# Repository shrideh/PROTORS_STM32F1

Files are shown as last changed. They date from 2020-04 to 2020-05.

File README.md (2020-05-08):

# PROTORS_STM32F1
This is a repository of our **open-source board** based on the *STM32F103C8 microcontroller from STMicroelectronics*.

<p align="center">
  
</p>

## Pinout and dimensions
For the available functions of every pin, we strongly encourage you to read the [microcontroller datasheet](https://www.st.com/resource/en/datasheet/stm32f103c8.pdf), or use `variant/variant.h` and `variant/PeripherialPins.c` files.

<p align="center">
  
</p>

## Electronics
* Whole *KiCad project* is available in `PROTORS_STM32F1` folder.

## Requirements
[Arduino](https://www.arduino.cc/)<br>
[Arduino_Core_STM32](https://github.com/stm32duino/Arduino_Core_STM32)<br>

This board is tested with
**Arduino IDE 1.8.12** and **Arduino_Core_STM32 1.8.0**.

## Installation & Usage
To use this board within [Arduino IDE](https://www.arduino.cc/en/main/software) you need [STM32 core support for Arduino](https://github.com/stm32duino/Arduino_Core_STM32). Every new board is called *variant*, to add this variant to list, you first need to find out where are source files on your system (follow [Where are sources](https://github.com/stm32duino/wiki/wiki/Where-are-sources#stm32-core-sources-files-location) page).

* Create folder `PROTORS_STM32F1` in `variants` folder and copy all files from this repositories `variant` folder (`ldscript.ld`, `PeripheralPins.c`, `PinNamesVar.h`, `variant.cpp`, and `variant.h`).
* Append `boards_additional.txt` content to `boards.txt` file (it is in same folder as `variant` folder), to declare the new variant.
* Restart *Arduino IDE* and try your new board. From ***Tools/Board*** menu select `Generic STM32F1 series` then from ***Tools/Board part number*** select `PROTORS STM32F1`. Set all of the rest options and upload sketch using ***STM32CubeProgrammer (SWD)*** (ST-LINK/V2 programmer).
* It is possible to customize some core definitions or compiler options by adding a file named `build_opt.h` in the sketch directory (follow [Build options](https://github.com/stm32duino/wiki/wiki/Customize-build-options-using-build_opt.h) page)

## License
Copyright (C) 2020 PROTORS  <info@protors.co>

Licensed under CERN-OHL-P version 2

You may redistribute and modify this documentation and make products
using it under the terms of the [CERN-OHL-P v2](https://ohwr.org/project/cernohl/wikis/Documents/CERN-OHL-version-2).
This documentation is distributed WITHOUT ANY EXPRESS OR IMPLIED
WARRANTY, INCLUDING OF MERCHANTABILITY, SATISFACTORY QUALITY
AND FITNESS FOR A PARTICULAR PURPOSE. Please see the CERN-OHL-P v2
for applicable conditions.

For more information view [LICENSE.txt](./LICENSE.txt) file.

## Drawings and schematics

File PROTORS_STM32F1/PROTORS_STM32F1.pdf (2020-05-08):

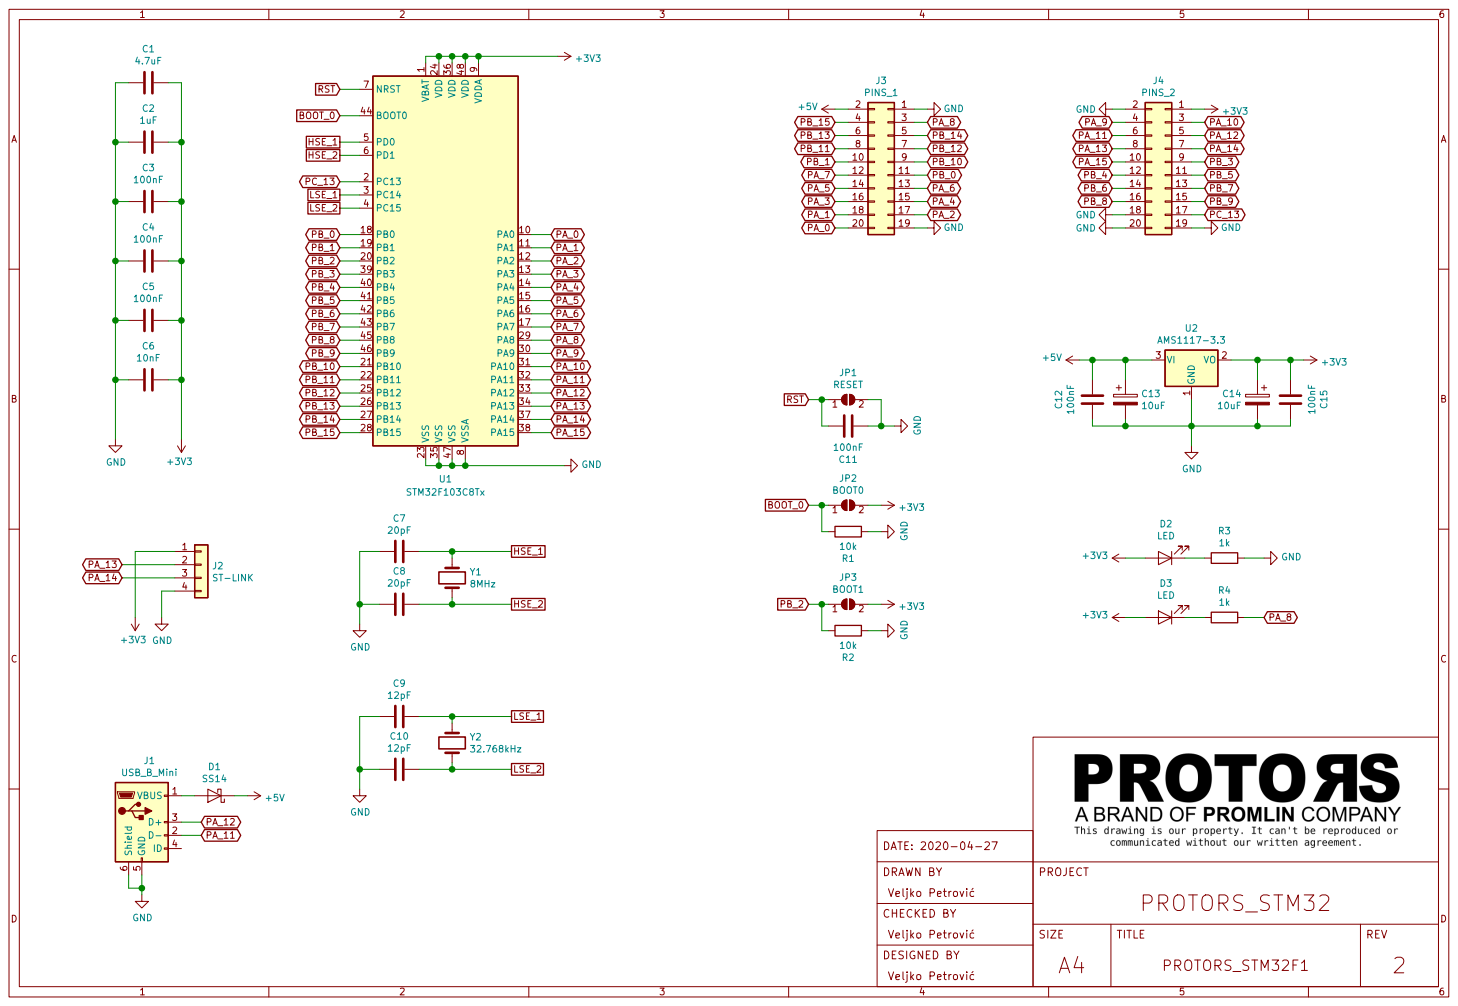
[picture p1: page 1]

DESIGNED BY CHECKED BY DRAWN BY

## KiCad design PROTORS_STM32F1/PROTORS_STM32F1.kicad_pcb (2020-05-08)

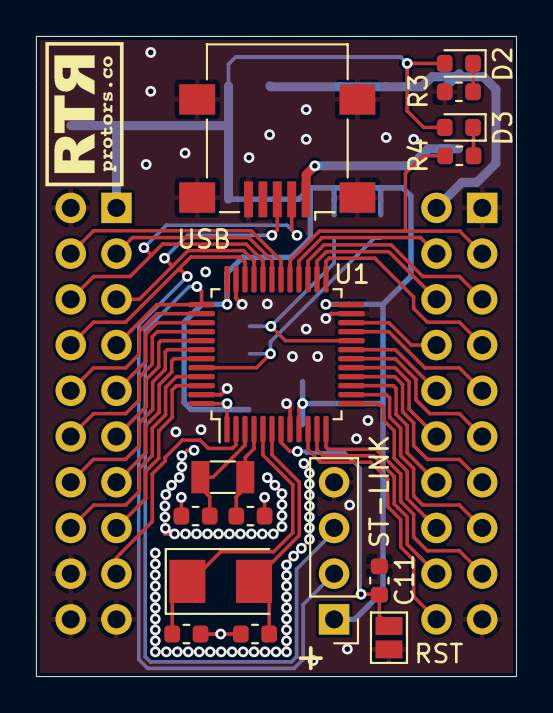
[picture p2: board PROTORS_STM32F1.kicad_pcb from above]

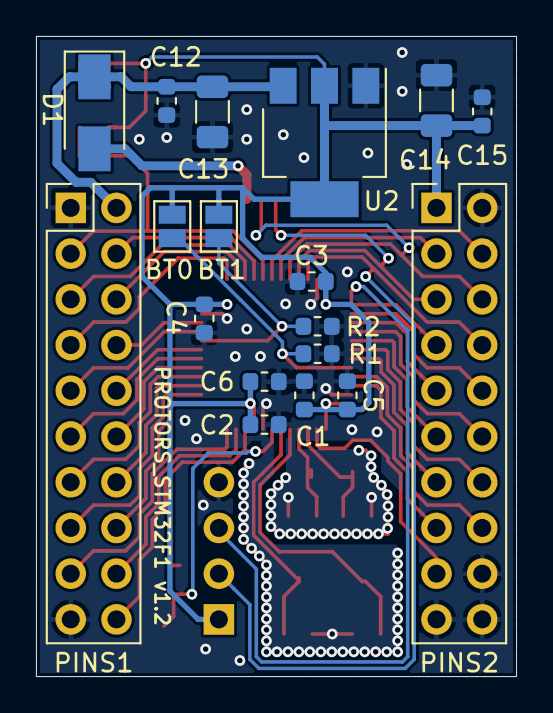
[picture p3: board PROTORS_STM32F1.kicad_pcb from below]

Board: 2 copper layers, 26.7 x 35.6 mm, 33 parts (18 on the bottom side), 45 nets.

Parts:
BT0: BOOT0; SolderJumper-2_P1.3mm_Open_Pad1.0x1.5mm
BT1: BOOT1; SolderJumper-2_P1.3mm_Open_Pad1.0x1.5mm
C1: 4.7uF; C_0603_1608Metric
C2: 1uF; C_0603_1608Metric
C3, C4, C5, C11, C12, C15: 100nF; C_0603_1608Metric
C6: 10nF; C_0603_1608Metric
C7, C8: 20pF; C_0603_1608Metric
C9, C10: 12pF; C_0603_1608Metric
C13, C14: 10uF; C_1206_3216Metric
D1: SS14; D_SMA
D2, D3: LED; LED_0603_1608Metric
PINS1: PINS_1; PinHeader_2x10_P2.54mm_Vertical
PINS2: PINS_2; PinHeader_2x10_P2.54mm_Vertical
R1, R2: 10k; R_0603_1608Metric
R3, R4: 1k; R_0603_1608Metric
RST: RESET; SolderJumper-2_P1.3mm_Open_Pad1.0x1.5mm
ST-LINK: ST-LINK; PinHeader_1x04_P2.54mm_Vertical
U1: STM32F103C8Tx; LQFP-48_7x7mm_P0.5mm
U2: AMS1117-3.3; SOT-223-3_TabPin2
USB: USB_B_Mini; USB_Mini-B_Lumberg_2486_01_Horizontal
Y1: 8MHz; Crystal_SMD_5032-2Pin_5.0x3.2mm
Y2: 32.768kHz; Crystal_SMD_3215-2Pin_3.2x1.5mm

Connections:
+3V3: BT0.2, BT1.2, C1.2, C2.2, C3.2, C4.2, C5.2, C6.2, C14.1, C15.1, D2.2, D3.2, PINS2.1, ST-LINK.1, U1.1, U1.9, U1.24, U1.36, U1.48, U2.2
+5V: C12.2, C13.1, D1.1, PINS1.2, U2.3
BOOT_0: BT0.1, R1.1, U1.44
GND: C1.1, C2.1, C3.1, C4.1, C5.1, C6.1, C7.2, C8.2, C9.2, C10.2, C11.1, C12.1, C13.2, C14.2, C15.2, PINS1.1, PINS1.19, PINS2.2, PINS2.18, PINS2.19, PINS2.20, R1.2, R2.2, R3.1, RST.2, ST-LINK.4, U1.8, U1.23, U1.35, U1.47, U2.1, USB.5, USB.6
HSE_1: C7.1, U1.5, Y1.1
HSE_2: C8.1, U1.6, Y1.2
LSE_1: C9.1, U1.3, Y2.1
LSE_2: C10.1, U1.4, Y2.2
unnamed: D1.2, USB.1
unnamed: D2.1, R3.2
unnamed: D3.1, R4.2
PA_0: PINS1.20, U1.10
PA_1: PINS1.18, U1.11
PA_2: PINS1.17, U1.12
PA_3: PINS1.16, U1.13
PA_4: PINS1.15, U1.14
PA_5: PINS1.14, U1.15
PA_6: PINS1.13, U1.16
PA_7: PINS1.12, U1.17
PA_8: PINS1.3, R4.1, U1.29
PA_9: PINS2.4, U1.30
PA_10: PINS2.3, U1.31
PA_11: PINS2.6, U1.32, USB.2
PA_12: PINS2.5, U1.33, USB.3
PA_13: PINS2.8, ST-LINK.2, U1.34
PA_14: PINS2.7, ST-LINK.3, U1.37
PA_15: PINS2.10, U1.38
PB_0: PINS1.11, U1.18
PB_1: PINS1.10, U1.19
PB_2: BT1.1, R2.1, U1.20
PB_3: PINS2.9, U1.39
PB_4: PINS2.12, U1.40
PB_5: PINS2.11, U1.41
PB_6: PINS2.14, U1.42
PB_7: PINS2.13, U1.43
PB_8: PINS2.16, U1.45
PB_9: PINS2.15, U1.46
PB_10: PINS1.9, U1.21
PB_11: PINS1.8, U1.22
PB_12: PINS1.7, U1.25
PB_13: PINS1.6, U1.26
PB_14: PINS1.5, U1.27
PB_15: PINS1.4, U1.28
PC_13: PINS2.17, U1.2
RST: C11.2, RST.1, U1.7

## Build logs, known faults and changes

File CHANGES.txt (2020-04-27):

--------------------
PROTORS_STM32F1 - Open-source board 
based on the STM32F103C8 microcontroller from STMicroelectronics.
--------------------

Release 1.0.0, 27.04.2020.

- Initial release

--------------------

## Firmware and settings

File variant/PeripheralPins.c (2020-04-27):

/*
 *******************************************************************************
 * Copyright (c) 2019, STMicroelectronics
 * All rights reserved.
 *
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
 * THIS SOFTWARE IS PROVIDED BY THE COPYRIGHT HOLDERS AND CONTRIBUTORS "AS IS"
 * AND ANY EXPRESS OR IMPLIED WARRANTIES, INCLUDING, BUT NOT LIMITED TO, THE
 * IMPLIED WARRANTIES OF MERCHANTABILITY AND FITNESS FOR A PARTICULAR PURPOSE ARE
 * DISCLAIMED. IN NO EVENT SHALL THE COPYRIGHT HOLDER OR CONTRIBUTORS BE LIABLE
 * FOR ANY DIRECT, INDIRECT, INCIDENTAL, SPECIAL, EXEMPLARY, OR CONSEQUENTIAL
 * DAMAGES (INCLUDING, BUT NOT LIMITED TO, PROCUREMENT OF SUBSTITUTE GOODS OR
 * SERVICES; LOSS OF USE, DATA, OR PROFITS; OR BUSINESS INTERRUPTION) HOWEVER
 * CAUSED AND ON ANY THEORY OF LIABILITY, WHETHER IN CONTRACT, STRICT LIABILITY,
 * OR TORT (INCLUDING NEGLIGENCE OR OTHERWISE) ARISING IN ANY WAY OUT OF THE USE
 * OF THIS SOFTWARE, EVEN IF ADVISED OF THE POSSIBILITY OF SUCH DAMAGE.
 *******************************************************************************
 * Automatically generated from STM32F103C(4-6)|(8-B)Tx.xml
 */
#include "Arduino.h"
#include "PeripheralPins.h"

/* =====
 * Note: Commented lines are alternative possibilities which are not used per default.
 *       If you change them, you will have to know what you do
 * =====
 */

//*** ADC ***

#ifdef HAL_ADC_MODULE_ENABLED
WEAK const PinMap PinMap_ADC[] = {
  {PA_0,  ADC1,  STM_PIN_DATA_EXT(STM_MODE_ANALOG, GPIO_NOPULL, 0, 0, 0)}, // ADC1_IN0
  //  {PA_0,  ADC2,  STM_PIN_DATA_EXT(STM_MODE_ANALOG, GPIO_NOPULL, 0, 0, 0)}, // ADC2_IN0
  {PA_1,  ADC1,  STM_PIN_DATA_EXT(STM_MODE_ANALOG, GPIO_NOPULL, 0, 1, 0)}, // ADC1_IN1
  //  {PA_1,  ADC2,  STM_PIN_DATA_EXT(STM_MODE_ANALOG, GPIO_NOPULL, 0, 1, 0)}, // ADC2_IN1
  {PA_2,  ADC1,  STM_PIN_DATA_EXT(STM_MODE_ANALOG, GPIO_NOPULL, 0, 2, 0)}, // ADC1_IN2
  //  {PA_2,  ADC2,  STM_PIN_DATA_EXT(STM_MODE_ANALOG, GPIO_NOPULL, 0, 2, 0)}, // ADC2_IN2
  {PA_3,  ADC1,  STM_PIN_DATA_EXT(STM_MODE_ANALOG, GPIO_NOPULL, 0, 3, 0)}, // ADC1_IN3
  //  {PA_3,  ADC2,  STM_PIN_DATA_EXT(STM_MODE_ANALOG, GPIO_NOPULL, 0, 3, 0)}, // ADC2_IN3
  {PA_4,  ADC1,  STM_PIN_DATA_EXT(STM_MODE_ANALOG, GPIO_NOPULL, 0, 4, 0)}, // ADC1_IN4
  //  {PA_4,  ADC2,  STM_PIN_DATA_EXT(STM_MODE_ANALOG, GPIO_NOPULL, 0, 4, 0)}, // ADC2_IN4
  {PA_5,  ADC1,  STM_PIN_DATA_EXT(STM_MODE_ANALOG, GPIO_NOPULL, 0, 5, 0)}, // ADC1_IN5
  //  {PA_5,  ADC2,  STM_PIN_DATA_EXT(STM_MODE_ANALOG, GPIO_NOPULL, 0, 5, 0)}, // ADC2_IN5
  {PA_6,  ADC1,  STM_PIN_DATA_EXT(STM_MODE_ANALOG, GPIO_NOPULL, 0, 6, 0)}, // ADC1_IN6
  //  {PA_6,  ADC2,  STM_PIN_DATA_EXT(STM_MODE_ANALOG, GPIO_NOPULL, 0, 6, 0)}, // ADC2_IN6
  {PA_7,  ADC1,  STM_PIN_DATA_EXT(STM_MODE_ANALOG, GPIO_NOPULL, 0, 7, 0)}, // ADC1_IN7
  //  {PA_7,  ADC2,  STM_PIN_DATA_EXT(STM_MODE_ANALOG, GPIO_NOPULL, 0, 7, 0)}, // ADC2_IN7
  {PB_0,  ADC1,  STM_PIN_DATA_EXT(STM_MODE_ANALOG, GPIO_NOPULL, 0, 8, 0)}, // ADC1_IN8
  //  {PB_0,  ADC2,  STM_PIN_DATA_EXT(STM_MODE_ANALOG, GPIO_NOPULL, 0, 8, 0)}, // ADC2_IN8
  {PB_1,  ADC1,  STM_PIN_DATA_EXT(STM_MODE_ANALOG, GPIO_NOPULL, 0, 9, 0)}, // ADC1_IN9
  //  {PB_1,  ADC2,  STM_PIN_DATA_EXT(STM_MODE_ANALOG, GPIO_NOPULL, 0, 9, 0)}, // ADC2_IN9
  {NC,    NP,    0}
};
#endif

//*** No DAC ***

//*** I2C ***

#ifdef HAL_I2C_MODULE_ENABLED
WEAK const PinMap PinMap_I2C_SDA[] = {
  {PB_7,  I2C1, STM_PIN_DATA(STM_MODE_AF_OD, GPIO_NOPULL, AFIO_NONE)},
  {PB_9,  I2C1, STM_PIN_DATA(STM_MODE_AF_OD, GPIO_NOPULL, AFIO_I2C1_ENABLE)},
#ifndef ARDUINO_BLUEPILL_F103C6
  {PB_11, I2C2, STM_PIN_DATA(STM_MODE_AF_OD, GPIO_NOPULL, AFIO_NONE)},
#endif
  {NC,    NP,    0}
};
#endif

#ifdef HAL_I2C_MODULE_ENABLED
WEAK const PinMap PinMap_I2C_SCL[] = {
  {PB_6,  I2C1, STM_PIN_DATA(STM_MODE_AF_OD, GPIO_NOPULL, AFIO_NONE)},
  {PB_8,  I2C1, STM_PIN_DATA(STM_MODE_AF_OD, GPIO_NOPULL, AFIO_I2C1_ENABLE)},
#ifndef ARDUINO_BLUEPILL_F103C6
  {PB_10, I2C2, STM_PIN_DATA(STM_MODE_AF_OD, GPIO_NOPULL, AFIO_NONE)},
#endif
  {NC,    NP,    0}
};
#endif

//*** PWM ***
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

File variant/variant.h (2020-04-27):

/*
 * PROTORS_STM32F1 
 *
 *******************************************************************************
 * Copyright (c) 2018, STMicroelectronics
 * All rights reserved.
 *
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
 * THIS SOFTWARE IS PROVIDED BY THE COPYRIGHT HOLDERS AND CONTRIBUTORS "AS IS"
 * AND ANY EXPRESS OR IMPLIED WARRANTIES, INCLUDING, BUT NOT LIMITED TO, THE
 * IMPLIED WARRANTIES OF MERCHANTABILITY AND FITNESS FOR A PARTICULAR PURPOSE ARE
 * DISCLAIMED. IN NO EVENT SHALL THE COPYRIGHT HOLDER OR CONTRIBUTORS BE LIABLE
 * FOR ANY DIRECT, INDIRECT, INCIDENTAL, SPECIAL, EXEMPLARY, OR CONSEQUENTIAL
 * DAMAGES (INCLUDING, BUT NOT LIMITED TO, PROCUREMENT OF SUBSTITUTE GOODS OR
 * SERVICES; LOSS OF USE, DATA, OR PROFITS; OR BUSINESS INTERRUPTION) HOWEVER
 * CAUSED AND ON ANY THEORY OF LIABILITY, WHETHER IN CONTRACT, STRICT LIABILITY,
 * OR TORT (INCLUDING NEGLIGENCE OR OTHERWISE) ARISING IN ANY WAY OUT OF THE USE
 * OF THIS SOFTWARE, EVEN IF ADVISED OF THE POSSIBILITY OF SUCH DAMAGE.
 *******************************************************************************
 */
#ifndef _VARIANT_ARDUINO_STM32_
#define _VARIANT_ARDUINO_STM32_

#ifdef __cplusplus
extern "C" {
#endif // __cplusplus

/*----------------------------------------------------------------------------
 *        Pins
 *----------------------------------------------------------------------------*/

// Left Side
#define PB9  0
#define PB8  1
#define PB7  2
#define PB6  3
#define PB5  4
#define PB4  5
#define PB3  6
#define PA15 7
#define PA12 8  // USB DP
#define PA11 9  // USB DM
#define PA10 10
#define PA9  11
#define PA8  12  // LED
#define PB15 13
#define PB14 14
#define PB13 15
#define PB12 16
// Right side
#define PC13 17
#define PC14 18
#define PC15 19
#define PA0  20 // A0
#define PA1  21 // A1
#define PA2  22 // A2
#define PA3  23 // A3
#define PA4  24 // A4
#define PA5  25 // A5
#define PA6  26 // A6
#define PA7  27 // A7
#define PB0  28 // A8
#define PB1  29 // A9
#define PB10 30
#define PB11 31
// Other
#define PB2  32 // BOOT1
#define PA13 33 // SWDI0
#define PA14 34 // SWCLK

// This must be a literal
#define NUM_DIGITAL_PINS        35
// This must be a literal with a value less than or equal to to MAX_ANALOG_INPUTS
#define NUM_ANALOG_INPUTS       10
#define NUM_ANALOG_FIRST        20

// On-board LED pin number
#define LED_BUILTIN             PA8

// SPI Definitions
#define PIN_SPI_SS              PA4
#define PIN_SPI_MOSI            PA7
#define PIN_SPI_MISO            PA6
#define PIN_SPI_SCK             PA5

// I2C Definitions
#define PIN_WIRE_SDA            PB7
#define PIN_WIRE_SCL            PB6

// Timer Definitions
// Use TIM6/TIM7 when possible as servo and tone don't need GPIO output pin
#define TIMER_TONE              TIM3
#define TIMER_SERVO             TIM2

// UART Definitions
#define SERIAL_UART_INSTANCE    1
// Default pin used for 'Serial' instance
// Mandatory for Firmata
#define PIN_SERIAL_RX           PA10
#define PIN_SERIAL_TX           PA9

#ifdef __cplusplus
} // extern "C"
#endif
/*----------------------------------------------------------------------------
 *        Arduino objects - C++ only
 *----------------------------------------------------------------------------*/

#ifdef __cplusplus
// These serial port names are intended to allow libraries and architecture-neutral
// sketches to automatically default to the correct port name for a particular type
// of use.  For example, a GPS module would normally connect to SERIAL_PORT_HARDWARE_OPEN,
// the first hardware serial port whose RX/TX pins are not dedicated to another use.
//
// SERIAL_PORT_MONITOR        Port which normally prints to the Arduino Serial Monitor
//
// SERIAL_PORT_USBVIRTUAL     Port which is USB virtual serial
//
// SERIAL_PORT_LINUXBRIDGE    Port which connects to a Linux system via Bridge library
//
// SERIAL_PORT_HARDWARE       Hardware serial port, physical RX & TX pins.
//
// SERIAL_PORT_HARDWARE_OPEN  Hardware serial ports which are open for use.  Their RX & TX
//                            pins are NOT connected to anything by default.
#define SERIAL_PORT_MONITOR     Serial
#define SERIAL_PORT_HARDWARE    Serial1
#endif

#endif /* _VARIANT_ARDUINO_STM32_ */
